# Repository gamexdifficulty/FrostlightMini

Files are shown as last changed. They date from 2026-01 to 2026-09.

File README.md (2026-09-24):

<p align="center">
  FrostlightMini Logo
</p>

<h1 align="center" id="title">FrostlightMini</h1>

<p align="center" id="description">
  A very small battery powered open source LED lamp.
</p>

<p align="center">
  
  
  
  
  
  
  
</p>

> ⚠️ This lamp is still work in progress and not a final product.

## ✨ Overview

FrostlightMini is a hand sized RGB LED lamp based on a custom PCB with an ESP32-C3 chip.
It can be used as a night light, party light, or small IoT device.

<p align="center">
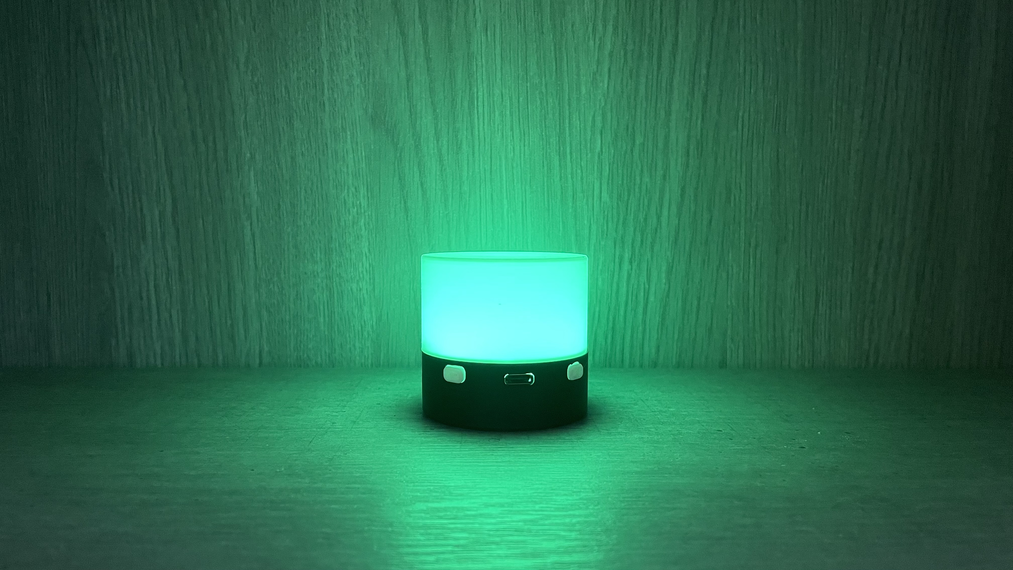
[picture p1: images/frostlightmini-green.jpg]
FrostlightMini Green
  
</p>

The project is fully open source and includes firmware, hardware design files, and documentation.

## 🔧 Hardware Features

<table>
<tr>
    <td width="60%" valign="top">

* Custom PCB  
* ESP32-C3 microcontroller with WiFi, ZigBee and Bluetooth  
* RGB LED  
* Battery powered  
* USB-C for charging and programming  
* Two physical buttons for control  

    </td>
    <td width="40%" align="center">
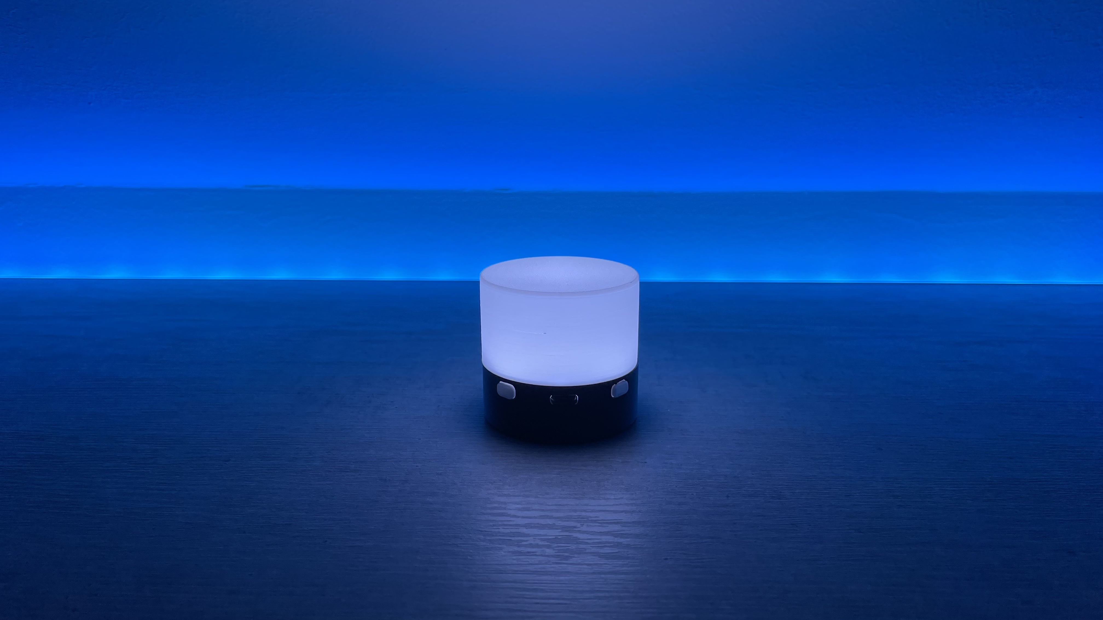
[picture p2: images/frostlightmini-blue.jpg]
FrostlightMini Blue
        
    </td>
</tr>
</table>

## 💡 Modes

FrostlightMini currently supports two operating modes:

* **Color Mode**
  Used to select and cycle through colors

* **Brightness Mode**
  Used to increase or decrease LED brightness

The lamp boots into **Color Mode** by default.

<p align="left">
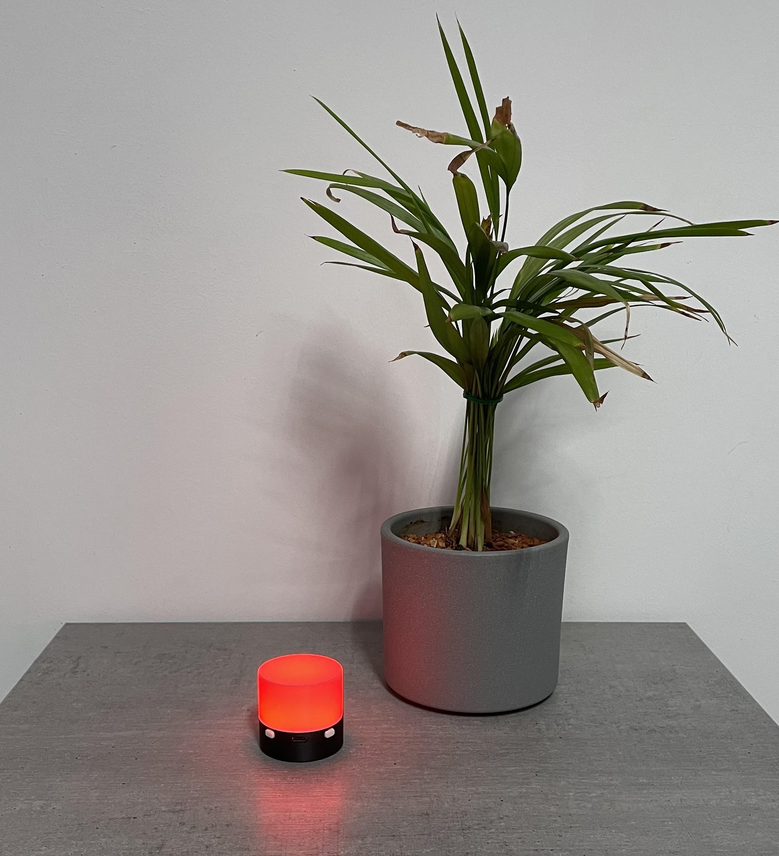
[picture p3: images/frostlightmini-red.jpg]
FrostlightMini Red
  
</p>

## 🎮 Controls

FrostlightMini is controlled using the **two buttons**.
Button behavior depends on the currently active mode.

### Button Overview

| Button | Purpose |
| --- | --- |
| Button 1 | Mode switching and power |
| Button 2 | Color or brightness control |

### Button 1, Mode & Power

<p align="left">
  Button 1
</p>

| Action | Effect |
| --- | --- |
| Short press | Switch between **Color Mode** and **Brightness Mode** |
| Hold ~1 second | Turn the lamp off |

Additional behavior:

* Entering **Color Mode** plays a color wheel animation
* Entering **Brightness Mode** is indicated by a short flash
* When powering off, the lamp flashes once, release the button to confirm shutdown

### Button 2, Mode Action Button

<p align="left">
  Button 2
</p>

#### In Color Mode

| Action | Effect |
| --- | --- |
| Short press | Switch directly to white |
| Hold | Cycle continuously through colors |

If the current color is white, holding the button starts cycling from red.

#### In Brightness Mode

| Action | Effect |
| --- | --- |
| Short press | Toggle between brightness increase and decrease |
| Hold | Continuously adjust brightness in the selected direction |

Additional behavior:

* A short flash indicates switching between increase/decrease
* Brightness Mode always starts in **decrease** mode

### 🔋 Charging Behavior

When the lamp is connected to power via USB-C, it enters a charging indicator mode.

| State | Indicator | How to exit |
| --- | --- | --- |
| Charging | Green pulsing light | Unplug USB-C or short-press any button |
| Fully charged | Blue pulsing light  | Short-press any button |

**Notes:**

* The charging indicator is shown automatically when the lamp is plugged in
* Pressing any button will return the lamp to normal operation while still plugged in

## 🔌 Power & Charging

* The lamp is powered by an internal lipo battery
* Charging is done via the USB-C port
* USB-C is also used for firmware flashing and development

## 🧑‍💻 Development

This project uses **PlatformIO** for firmware development.

Typical workflow:

* Open the project in PlatformIO
* Connect the lamp via USB-C
* Build and upload the firmware

## 📁 Repository Structure

* `firmware/` – ESP32-C3 firmware
* `hardware/` – PCB and hardware design files
* `images/` – Images used in this README
* `documentation/` – Additional documentation (if available)

## 🚧 Project Status

FrostlightMini is under active development.

Expect:

* Breaking changes
* Incomplete features
* Hardware and firmware revisions

Feedback, testing, and contributions are welcome.

## 🗺️ Roadmap

- [x] 0.1.0 | Basic functionality
- [x] 0.2.0 | Storing led state
- [x] 0.3.0 | Serial communication
- [x] 0.4.0 | Serial configuration
- [ ] 0.5.0 | Rewrite/Refactoring for better performance
- [ ] 0.6.0 | Permanent effects
- [ ] 0.7.0 | Desktop app
- [ ] 0.8.0 | Wireless communication
- [ ] 0.9.0 | Device synchronization
- [ ] 1.0.0 | Device hosted web app

## 🤝 Contributing

Contributions are appreciated.

You can help by:

* Reporting bugs
* Suggesting features
* Improving documentation
* Submitting pull requests

Please open an issue before making major changes.

## 📜 License

This project is licensed under the license specified in the repository.
See the `LICENSE` file for details.

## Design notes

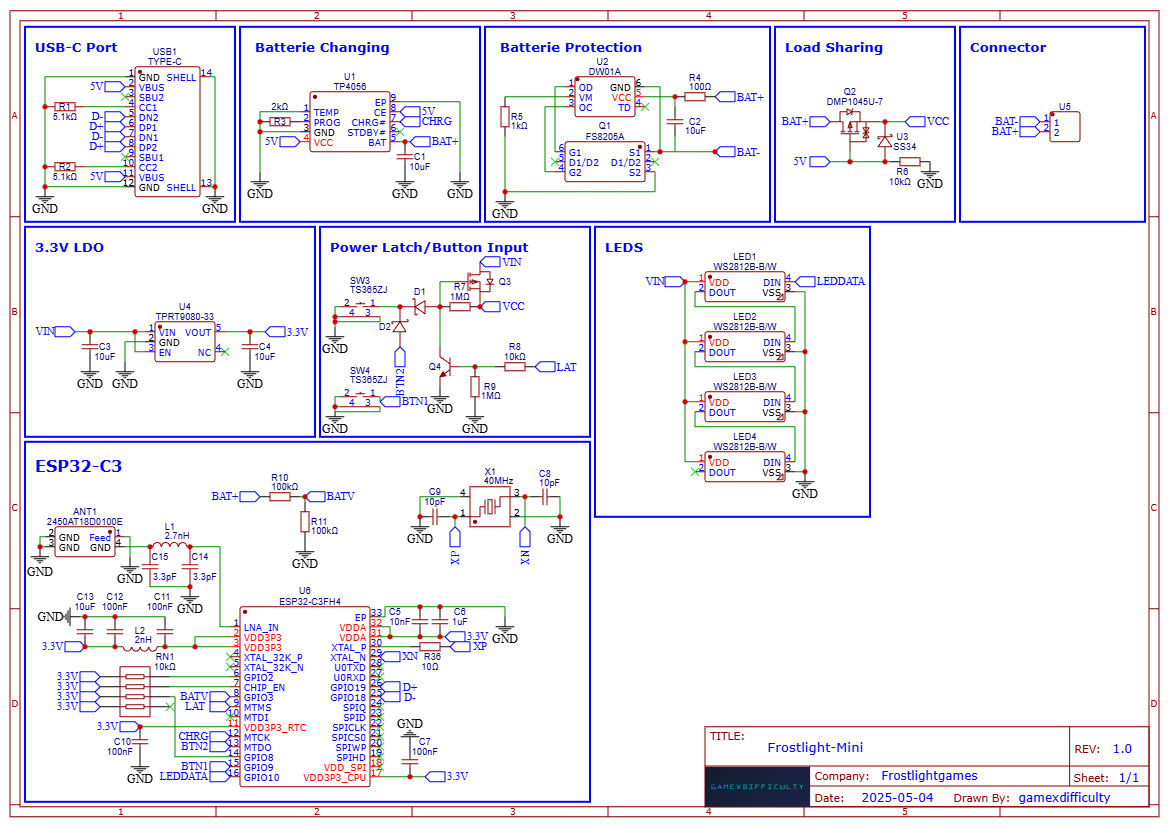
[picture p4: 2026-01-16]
hardware/schematics/frostlightmini-schematic.png

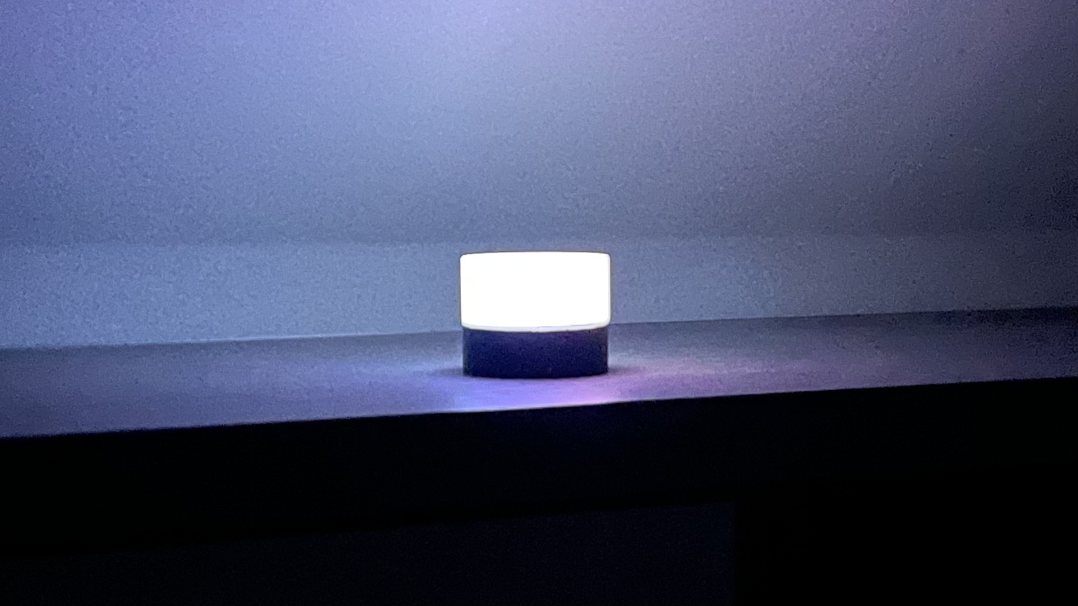
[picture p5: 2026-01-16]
images/lamp-white.jpg

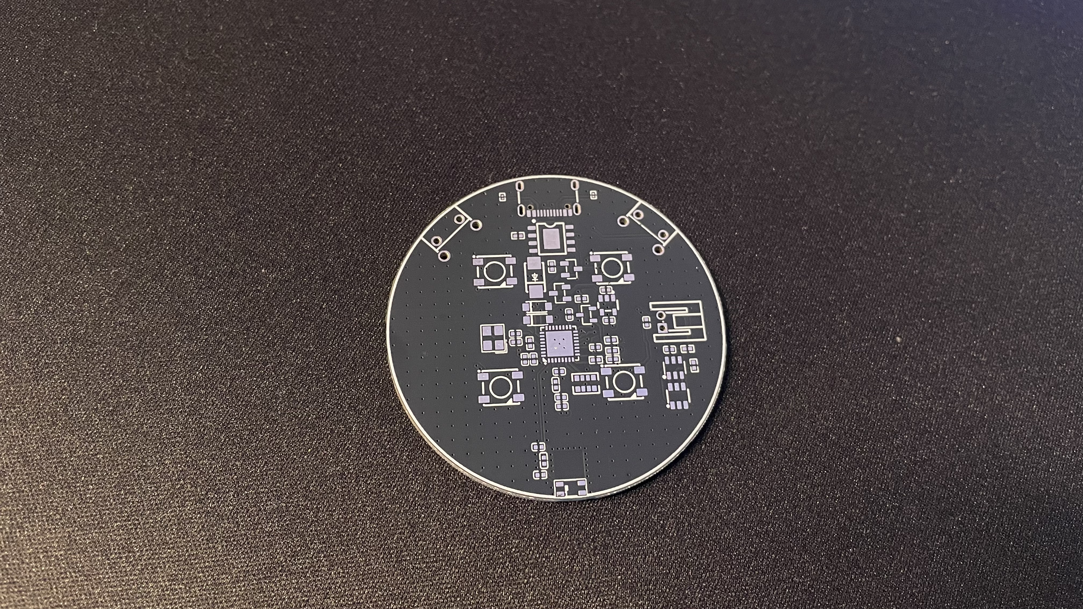
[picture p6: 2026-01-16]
images/pcb-top.jpg

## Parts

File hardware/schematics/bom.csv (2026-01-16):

ID | Name | Designator | Footprint | Quantity | Manufacturer Part | Manufacturer | Supplier | Supplier Part | Price
1 | 2450AT18D0100E | ANT1 | ANT-SMD_4P-L3.2-W1.6 | 1 | 2450AT18D0100E | JOHANSON(约翰逊) | LCSC | C2917718 | 0.674
2 | 10uF | C1,C2,C3,C4,C13 | C0402 | 5 | CL05A106MQ5NUNC | SAMSUNG(三星) | LCSC | C15525 | 0.005
3 | 10nF | C5 | C0402 | 1 | CC0402KRX7R9BB103 | YAGEO(国巨) | LCSC | C60133 | 0.001
4 | 1uF | C6 | C0402 | 1 | CL05A105KP5NNNC | SAMSUNG(三星) | LCSC | C14445 | 0.002
5 | 100nF | C7,C10,C11,C12 | C0402 | 4 | CL05B104KO5NNNC | SAMSUNG(三星) | LCSC | C1525 | 0.001
6 | 10pF | C8,C9 | C0402 | 2 | 0402CG100J500NT | FH(风华) | LCSC | C1545 | 0.001
7 | 3.3pF | C14,C15 | C0402 | 2 | GJM1555C1H3R3WB01D | muRata(村田) | LCSC | C88892 | 0.04
8 | BAT42W | D1,D2 | SOD-123_L2.8-W1.8-LS3.7-RD | 2 | BAT42W | SHIKUES(时科) | LCSC | C130886 | 0.027
9 | 2.7nH | L1 | L0402 | 1 | LQG15HS2N7S02D | muRata(村田) | LCSC | C77108 | 0.007
10 | 2nH | L2 | L0402 | 1 | LQG15HS2N0S02D | muRata(村田) | LCSC | C18216 | 0.008
11 | WS2812B-B/W | LED1,LED2,LED3,LED4 | LED-SMD_4P-L5.0-W5.0-TL_WS2812B-B | 4 | WS2812B-B/T | worldsemi | LCSC | C2761795 | 0.084
12 | FS8205A | Q1 | SOT-23-6_L2.9-W1.6-P0.95-LS2.8-BR | 1 | FS8205A | TECH PUBLIC(台舟) | LCSC | C2830320 | 0.046
13 | DMP1045U-7 | Q2 | SOT-23-3_L2.9-W1.3-P1.90-LS2.4-BR | 1 | DMP1045U-7 | DIODES(美台) | LCSC | C177033 | 0.075
14 | SI2301_C2891731 | Q3 | SOT-23-3_L2.9-W1.3-P1.90-LS2.4-BR | 1 | SI2301 | YONGYUTAI(永裕泰) | LCSC | C2891731 | 0.013
15 | S8050_C20069125 | Q4 | SOT-23-3_L2.9-W1.3-P1.90-LS2.3-BR | 1 | S8050 | 宏嘉诚 | LCSC | C20069125 | 0.01
16 | 5.1kΩ | R1,R2 | R0201 | 2 | 0201WMF5101TEE | UNI-ROYAL(厚声) | LCSC | C270344 | 0.001
17 | 2kΩ | R3 | R0402 | 1 | 0402WGF2001TCE | UNI-ROYAL(厚声) | LCSC | C4109 | 0.001
18 | 100Ω | R4 | R0402 | 1 | 0402WGF1000TCE | UNI-ROYAL(厚声) | LCSC | C25076 | 0.001
19 | 1kΩ | R5 | R0402 | 1 | RC0402FR-071KL | YAGEO(国巨) | LCSC | C106235 | 0.001
20 | 10kΩ | R6,R8 | R0402 | 2 | RC0402FR-0710KL | YAGEO(国巨) | LCSC | C60490 | 0.001
21 | 1MΩ | R7,R9 | R0402 | 2 | RC0402FR-071ML | YAGEO(国巨) | LCSC | C138033 | 0.001
22 | 100kΩ | R10,R11 | R0402 | 2 | RC0402FR-07100KL | YAGEO(国巨) | LCSC | C60491 | 0.001
23 | 10Ω | R36 | R0402 | 1 | 0402WGF100JTCE | UNI-ROYAL(厚声) | LCSC | C25077 | 0.001
24 | 10kΩ | RN1 | RES-ARRAY-SMD_0603-8P-L3.2-W1.6-BL | 1 | 4D03WGJ0103T5E | UNI-ROYAL(厚声) | LCSC | C29718 | 0.006
25 | TS365ZJ | SW3,SW4 | KEY-TH_TS365ZJ | 2 | TS365ZJ | SHOU HAN(首韩) | LCSC | C557598 | 0.051
26 | TP4056 | U1 | ESOP-8_L4.9-W3.9-P1.27-LS6.0-BL-EP | 1 | TP4056 | TECH PUBLIC(台舟) | LCSC | C5311018 | 0.087
27 | DW01A | U2 | SOT-23-6_L2.9-W1.6-P0.95-LS2.8-BL | 1 | DW01A | PUOLOP(迪浦) | LCSC | C351410 | 0.041
28 | SS34 | U3 | DO-214AC_L4.3-W2.7-LS5.2-RD | 1 | SS34 | YFW(佑风微) | LCSC | C3039962 | 0.036
29 | TPRT9080-33 | U4 | SOT-23-5_L2.9-W1.6-P0.95-LS2.8-BR | 1 | TPRT9080-33GJ5 | TECH PUBLIC(台舟) | LCSC | C2959864 | 0.105
30 | S2B-PH-K-S(LF)(SN) | U5 | CONN-TH_S2B-PH-K-S-LF-SN | 1 | S2B-PH-K-S(LF)(SN) | JST | LCSC | C173752 | 0.035
31 | ESP32-C3FH4 | U6 | QFN-32_L5.0-W5.0-P0.50-TL-EP3.7 | 1 | ESP32-C3FH4 | ESPRESSIF(乐鑫) | LCSC | C2858491 | 2.334
32 | TYPE-C | USB1 | USB-C-SMD_TYPE-C-6PIN-2MD-073 | 1 | TYPE-C 16PIN 2MD(073) | SHOU HAN(首韩) | LCSC | C2765186 | 0.063
33 | 40MHz | X1 | CRYSTAL-SMD_4P-L3.2-W2.5-BL | 1 | 7B040000M01 | HD(浩都频率) | LCSC | C655034 | 0.064

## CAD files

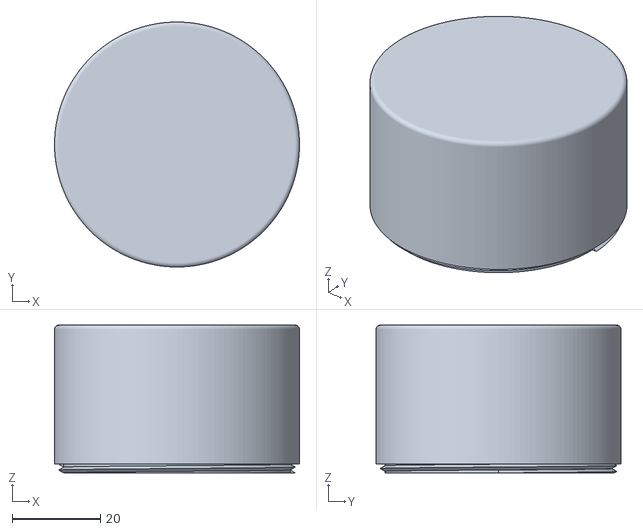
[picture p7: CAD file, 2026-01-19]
hardware/case/frostlightmini-top.stl
55.5 x 55.5 x 33.5

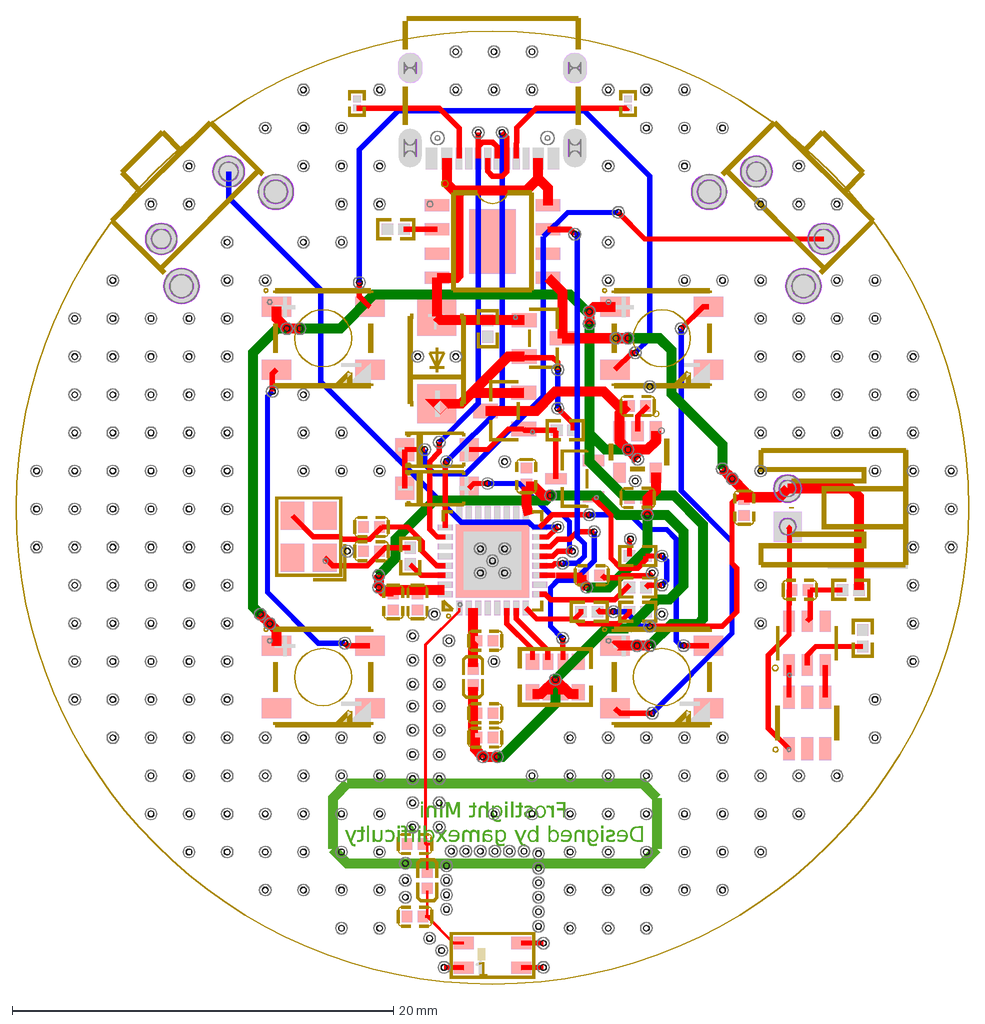
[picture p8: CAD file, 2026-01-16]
hardware/pcb/frostlightmini-pcb.dxf
gamexdifficulty
Frostlight Mini
Designed by
1

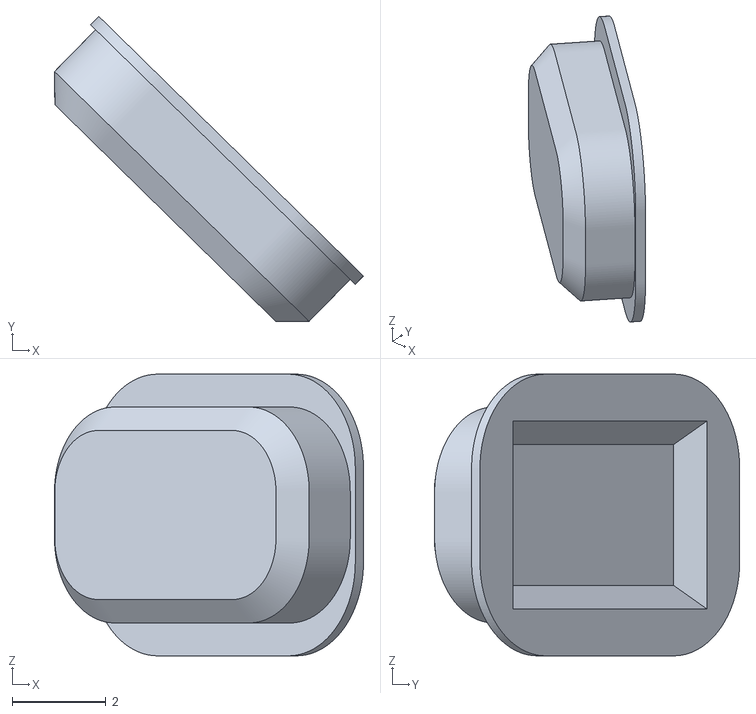
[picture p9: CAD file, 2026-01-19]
hardware/case/frostlightmini-button.stl
6.58 x 6.50 x 6.00

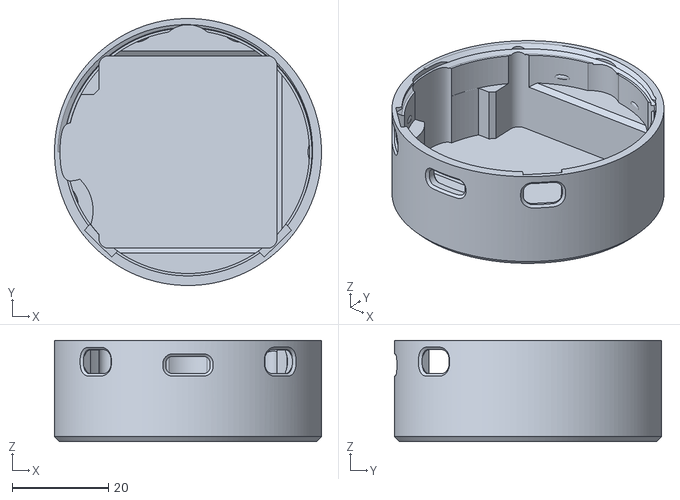
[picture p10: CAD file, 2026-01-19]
hardware/case/frostlightmini-case.stl
55.5 x 55.5 x 21.0

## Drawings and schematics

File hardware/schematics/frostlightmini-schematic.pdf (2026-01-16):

## USB-C Port

Batterie Changing | Batterie Protection

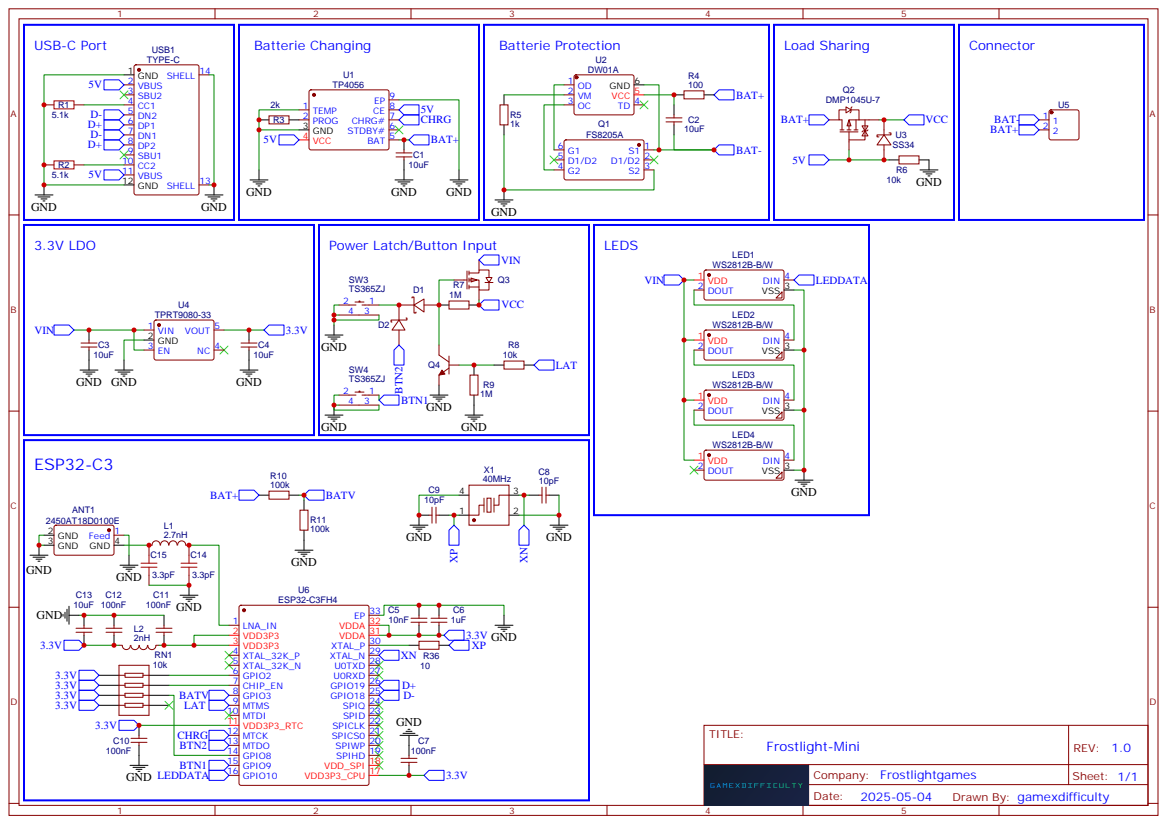
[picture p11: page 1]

Power Latch/Button Input

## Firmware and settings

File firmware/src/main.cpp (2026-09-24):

#include <stdio.h>
#include <cmath>
#include <algorithm>
#include <iostream>
#include <string>

#include "esp_log.h"
#include "esp_timer.h"
#include "freertos/FreeRTOS.h"
#include "freertos/task.h"

#include "pin.h"
#include "leds.h"
#include "serial.h"
#include "storage.h"

static const uint32_t LOOP_DELAY_MS = 20;
static const uint16_t SHORT_PRESS = 350;

extern "C" void app_main(void)
{
    const char* firmwareVersion = "0.4.0";

    Pin pins;
    Leds leds;
    Storage storage;
    LedConfig config;
    Serial serial;

    float hue = 0.0f;

    uint32_t lastTime = 0;
    uint32_t deltaTime = 0;
    uint16_t shutdownFlashCooldown = 0;

    bool shutdown = false;
    bool charging = false;
    bool interaction = false;

    uint8_t mode = 0;
    uint8_t savedMode = 0;
    uint8_t brightnessMode = 0;

    leds.clear();

    uint8_t savedColor[3] = {leds.getLedColor(0)[0],leds.getLedColor(0)[1],leds.getLedColor(0)[2]};

    if (!storage.loadLedConfig(config)) {
        leds.setBrightness(255);
        leds.setColor(0,0,0,0);
        leds.setColor(1,0,0,0);
        leds.setColor(2,0,0,0);
        leds.setColor(3,0,0,0);
        leds.startFadeToColor(255,255,255);
        savedColor[0] = 255;
        savedColor[1] = 255;
        savedColor[2] = 255;
    } else {
        leds.setBrightness(config.brightness);
        leds.setColor(0,0,0,0);
        leds.setColor(1,0,0,0);
        leds.setColor(2,0,0,0);
        leds.setColor(3,0,0,0);
        leds.startFadeToColor(config.r,config.g,config.b);
        float h, s, v;
        leds.rgbToHsv(config.r, config.g, config.b,h,s,v);
        hue = h/360.0f;
        savedColor[0] = config.r;
        savedColor[1] = config.g;
        savedColor[2] = config.b;
    }

    leds.update(0);

    while (true) {
        uint32_t now = esp_timer_get_time() / 1000;
        if (lastTime == 0) {lastTime = now;}
        deltaTime = now-lastTime;
        lastTime = now;
        pins.update(now);
        serial.update();

        if (pins.getBatteryPercentage() <= 0) { shutdown = true; }
        if (pins.getButton1HeldTimer() >= 1000 && shutdownFlashCooldown == 0) { 
            leds.startShortFlashEffect(); 
            shutdownFlashCooldown = 3000;
        }
        if (shutdownFlashCooldown != 0) { shutdownFlashCooldown = std::max<uint16_t>(0,shutdownFlashCooldown-deltaTime); }
        if (pins.getButton1Released() || pins.getButton2Released()) { interaction = true; } else { interaction = false; }
        if (pins.getButton1Released() && pins.getButton1HeldTimer() >= 1000) { shutdown = true; }
        if (pins.getButton1Released() && pins.getButton1HeldTimer() <= SHORT_PRESS) {
            if (mode < 2 && !charging && interaction) {
                mode = mode == 0 ? 1 : 0;
                if (mode == 0) {
                    leds.startColorWheel();
                }
                if (mode == 1) {
                    brightnessMode = 0;
                    leds.startShortFlashEffect();
                }
            }
        }

        if (mode == 0) { // color
            if (pins.getButton2Released() && pins.getButton2HeldTimer() < SHORT_PRESS) { 
                if (leds.getLedColor(0)[0] != 255 || leds.getLedColor(0)[1] != 255 || leds.getLedColor(0)[2] != 255) { // set to white
                    leds.startFadeToColor(255,255,255);
                    config.r = 255;
                    config.g = 255;
                    config.b = 255;
                    config.brightness = leds.getBrightness();
                    storage.saveLedConfig(config);
                }
            }
            if (pins.getButton2Pressed() && pins.getButton2HeldTimer() >= SHORT_PRESS) { // change color
                if (leds.getLedColor(0)[0] == 255 && leds.getLedColor(0)[1] == 255 && leds.getLedColor(0)[2] == 255 && leds.getEffectCount() == 0) { // reset from white to red
                    leds.startFadeToColor(255,0,0);
                    hue = 0.0f;
                }
                
                if (leds.getEffectCount() == 0) {
                    hue += 0.0025f; // cycle color
                    if (hue >= 1.0f) hue -= 1.0f;
                    
                    uint8_t r, g, b;
                    leds.hsvToRgb(hue, 1.0f, 1.0f, r, g, b);
                    config.r = r;
                    config.g = g;
                    config.b = b;
                    config.brightness = leds.getBrightness();
                    storage.saveLedConfig(config);

                    for (int i = 0; i < 4; i++) {
                        leds.setColor(i, r, g, b);
                    }
                }
            }
        }
        
        if (mode == 1) { // brightness up/down
            if (pins.getButton2Released() && pins.getButton2HeldTimer() < SHORT_PRESS) { 
                brightnessMode = brightnessMode == 0 ? 1 : 0;
                if (brightnessMode == 0) { leds.startShortFlashEffect(); }
                if (brightnessMode == 1) { leds.startShortFlashEffect(); }
            }
            if (pins.getButton2Pressed() && pins.getButton2HeldTimer() >= SHORT_PRESS) {
                uint8_t brightness = leds.getBrightness();
                if (brightnessMode == 0) { leds.setBrightness(std::max<uint8_t>(2,brightness - 1)); }     // brightness down
                if (brightnessMode == 1) { leds.setBrightness(std::min<uint8_t>(254,brightness + 1)); }   // brightness up

                config.r = leds.getLedColor(0)[0];
                config.g = leds.getLedColor(0)[1];
                config.b = leds.getLedColor(0)[2];
                config.brightness = leds.getBrightness();
                storage.saveLedConfig(config);
            }
        }

        if (mode == 2) { // charge
            if (leds.getEffectCount() == 0 && shutdown == false) { leds.startBreathEffect(); }
            if (!pins.isCharging() && charging && pins.getBatteryPercentage() >= 85) {
                mode = 3;
                leds.startFadeToColor(0,0,255);
            }
        }

        if (mode == 3) { // fully charged
            if (leds.getEffectCount() == 0 && shutdown == false) {
                leds.startBreathEffect();
            }
        }

        if (pins.isCharging() && !charging) { // check if charging
            savedMode = mode;
            const uint8_t* color = leds.getLedColor(0);
           
            if (color[0] != 0 || color[1] != 0 || color[2] != 0) {
                savedColor[0] = color[0];
                savedColor[1] = color[1]; 
                savedColor[2] = color[2];
            }
            leds.startFadeToColor(0,255,0);
            mode = 2;
        }

        auto tokens = serial.read();
        int tokenSize = tokens.size();
        if (!tokens.empty()) {
            if(tokens[0] == "off") {
                ESP_LOGI("Frostlight", "Shuting device off");
                shutdown = true;
            }

            if (tokens[0] == "set" && tokenSize > 1) {
                if (tokens[1] == "brightness" && tokenSize == 3) {
                    uint8_t brightness = stoi(tokens[2]);
                    if (brightness > 0) {
                        leds.setBrightness(brightness);
                        ESP_LOGI("Frostlight", "Set Brightness to %d", brightness);
                    } else {
                        ESP_LOGI("Frostlight", "Brightness must be between 1 and 255");
                    }
                } else if (tokens[1] == "color" && tokenSize == 5) {
                    uint8_t r = stoi(tokens[2]);
                    uint8_t g = stoi(tokens[3]);
                    uint8_t b = stoi(tokens[4]);
                    if (r == 0 && b == 0 && b == 0) {
                        ESP_LOGI("Frostlight", "Color must not be 0 0 0!");
                    } else {
                        for (int i=0; i<4; i++){
                            leds.setColor(i,r,g,b);
                        }
                        ESP_LOGI("Frostlight", "Set Color to R:%d G:%d B:%d", r,g,b);
                    }
                }
            }

            if (tokens[0] == "get" && tokenSize > 1) {
                if(tokens[1] == "version") {
                    ESP_LOGI("Frostlight", "%s", firmwareVersion);
                } else if(tokens[1] == "color") {
                    ESP_LOGI("Frostlight", "%d, %d, %d", leds.getLedColor(0)[0], leds.getLedColor(0)[1], leds.getLedColor(0)[2]);
                } else if(tokens[1] == "brightness") {
                    ESP_LOGI("Frostlight", "%d", leds.getBrightness());
                } else if(tokens[1] == "effectcount") {    
                    ESP_LOGI("Frostlight", "%d", leds.getEffectCount());
                }else if(tokens[1] == "temperature") {    
                    ESP_LOGI("Frostlight", "%.3f", pins.getChipTemperature());
                } else if(tokens[1] == "battery") {
                    ESP_LOGI("Frostlight", "%.3f, %d, %s", pins.getADC(), pins.getBatteryPercentage(), pins.isCharging() ? "true" : "false"); // voltage, percentage, charging 
                } else if(tokens[1] == "remaining") {
                    float brightness = leds.getBrightness() / 255.0f;

                    float r = (leds.getLedColor(0)[0] / 255.0f) * brightness;
                    float g = (leds.getLedColor(0)[1] / 255.0f) * brightness;
                    float b = (leds.getLedColor(0)[2] / 255.0f) * brightness;

                    float red   = 20.0f * r;
                    float green = 20.0f * g;
                    float blue  = 20.0f * b;

                    float current = (red + green + blue) * 4.0f;

                    float remaining = 0.0f;
                    if (current > 0.001f) {
                        remaining = (2000.0f / current) * (pins.getBatteryPercentage() / 100.0f);
                    }

                    ESP_LOGI("Frostlight", "%.3f %.3f", remaining, current); // hours, current in mAh

                }
            }
        }

        if (((!pins.isCharging() && charging) && mode == 2) || (interaction && mode > 1)) { // unplugged or interacted with
            mode = savedMode;
            leds.startFadeToColor(savedColor[0], savedColor[1], savedColor[2]);
        }

        charging = pins.isCharging();

        if (shutdown) { // shutoff
            leds.darkenOff();
            if (leds.getBrightness() <= 0) {
                pins.turnOff();
            }
        }

        leds.update(deltaTime);
        vTaskDelay(pdMS_TO_TICKS(LOOP_DELAY_MS));
    }
}

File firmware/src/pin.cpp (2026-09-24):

#include "pin.h"
#include "math.h"

#include "driver/gpio.h"
#include "driver/adc.h"
#include "driver/temperature_sensor.h"
#include "esp_adc_cal.h"
#include "esp_log.h"

/* GPIO definitions */
#define PWR_GPIO GPIO_NUM_4
#define CHRG_GPIO GPIO_NUM_6
#define BUTTON1GPIO GPIO_NUM_7
#define BUTTON2GPIO GPIO_NUM_9

/* ADC definitions */
#define ADC_CHANNEL ADC1_CHANNEL_3
#define ADC_WIDTH ADC_WIDTH_BIT_12
#define ADC_ATTEN ADC_ATTEN_DB_11
#define DEFAULT_VREF 1100

static esp_adc_cal_characteristics_t adc_chars;

Pin::Pin() {
    /* Power GPIO */
    gpio_config_t pwr_conf = {};
    pwr_conf.pin_bit_mask = (1ULL << PWR_GPIO);
    pwr_conf.mode = GPIO_MODE_OUTPUT;
    pwr_conf.pull_up_en = GPIO_PULLUP_DISABLE;
    pwr_conf.pull_down_en = GPIO_PULLDOWN_DISABLE;
    pwr_conf.intr_type = GPIO_INTR_DISABLE;
    gpio_config(&pwr_conf);
    gpio_set_level(PWR_GPIO, 1);

    /* CHRG pin */
    gpio_config_t chrg_conf = {};
    chrg_conf.pin_bit_mask = (1ULL << CHRG_GPIO);
    chrg_conf.mode = GPIO_MODE_INPUT;
    chrg_conf.pull_up_en = GPIO_PULLUP_ENABLE;
    chrg_conf.pull_down_en = GPIO_PULLDOWN_DISABLE;
    chrg_conf.intr_type = GPIO_INTR_DISABLE;
    gpio_config(&chrg_conf);

    /* Button GPIOs */
    gpio_config_t btn_conf = {};
    btn_conf.pin_bit_mask =
        (1ULL << BUTTON1GPIO) |
        (1ULL << BUTTON2GPIO);
    btn_conf.mode = GPIO_MODE_INPUT;
    btn_conf.pull_up_en = GPIO_PULLUP_ENABLE;
    btn_conf.pull_down_en = GPIO_PULLDOWN_DISABLE;
    btn_conf.intr_type = GPIO_INTR_DISABLE;
    gpio_config(&btn_conf);

    /* ADC setup */
    adc1_config_width(ADC_WIDTH);
    adc1_config_channel_atten(ADC_CHANNEL, ADC_ATTEN);

    esp_adc_cal_characterize(
        ADC_UNIT_1,
        ADC_ATTEN,
        ADC_WIDTH,
        DEFAULT_VREF,
        &adc_chars);

    /* Temperature setup */
    temp_handle = NULL;
    temperature_sensor_config_t temp_sensor = {
        .range_min = -10,
        .range_max = 80,
    };
    ESP_ERROR_CHECK(temperature_sensor_install(&temp_sensor, &temp_handle));
    ESP_ERROR_CHECK(temperature_sensor_enable(temp_handle));

}

void Pin::update(uint32_t timer) {
    bool btn1Now = (gpio_get_level(BUTTON1GPIO) == 0);
    bool btn2Now = (gpio_get_level(BUTTON2GPIO) == 0);

    if (!button1Initialized) {
        button1Initialized = !btn1Now;
    } else {
        button1Released = (button1Pressed && !btn1Now);
        button1Pressed = btn1Now;
    }

    if (!button2Initialized) {
        button2Initialized = !btn2Now;
    } else {
        button2Released = (button2Pressed && !btn2Now);
        button2Pressed = btn2Now;
    }

    if (button1Pressed && button1HeldStartTimer == 0) { button1HeldStartTimer = timer; }
    if (button2Pressed && button2HeldStartTimer == 0) { button2HeldStartTimer = timer; }

    if (button1HeldStartTimer != 0) { button1HeldTimer = timer - button1HeldStartTimer; }
    if (button2HeldStartTimer != 0) { button2HeldTimer = timer - button2HeldStartTimer; }

    if (!button1Pressed and !button1Released and button1HeldStartTimer > 0) {
        button1HeldStartTimer = 0;
        button1HeldTimer = 0;
    }

    if (!button2Pressed and !button2Released and button2HeldStartTimer > 0) {
        button2HeldStartTimer = 0;
        button2HeldTimer = 0;
    }

    if (monitorBattery && timer - batteryMonitoringTimer > 3000) {
        ESP_LOGI("Frostlight", "Battery voltage: %.3f | Battery charge percentage: %d | Charging: %s", getADC(), getBatteryPercentage(),isCharging() ? "true" : "false");
        batteryMonitoringTimer = timer;
    }
}

bool Pin::getButton1Pressed() { return button1Pressed; }
bool Pin::getButton2Pressed() { return button2Pressed; }
bool Pin::getButton1Released() { return button1Released; }
bool Pin::getButton2Released() { return button2Released; }

uint32_t Pin::getButton1HeldTimer() { return button1HeldTimer; }
uint32_t Pin::getButton2HeldTimer() { return button2HeldTimer; }

float Pin::getADC() {
    int raw = adc1_get_raw(ADC_CHANNEL);
    uint32_t mv = esp_adc_cal_raw_to_voltage(raw, &adc_chars);

    float adc_voltage = mv / 1000.0f;
    return adc_voltage * 2.0f;
}

int Pin::getBatteryPercentage() {
    float v = getADC();
    int percent = 100.0f * powf((v - 3.3f) / 0.9f, 1.6f);
    
    if (percent > 100) percent = 100;
    if (percent < 0) percent = 0;
    
    return percent;
}

float Pin::getChipTemperature() {
    float tsens_out = 0;
    temperature_sensor_get_celsius(temp_handle, &tsens_out);
    return tsens_out;
}

bool Pin::isCharging() { return gpio_get_level(CHRG_GPIO) == 0; }
void Pin::turnOff() { gpio_set_level(PWR_GPIO, 0); }

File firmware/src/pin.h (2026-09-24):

#ifndef _PIN_H_
#define _PIN_H_

#include <cstdint>
#include "driver/temperature_sensor.h"

class Pin {
private:
    bool monitorBattery = false;
    bool button1Pressed = false;
    bool button2Pressed = false;
    bool button1Released = false;
    bool button2Released = false;
    bool button1Initialized = false;
    bool button2Initialized = false;
    uint32_t button1HeldTimer = 0;
    uint32_t button2HeldTimer = 0;
    uint32_t button1HeldStartTimer = 0;
    uint32_t button2HeldStartTimer = 0;
    uint32_t batteryMonitoringTimer = 0;
    temperature_sensor_handle_t temp_handle = NULL;
    
public:
    Pin();
    void setBatteryMonitoring(bool state) {monitorBattery = state;};
    void update(uint32_t timer);
    void turnOff();

    float getADC();
    bool isCharging();
    int getBatteryPercentage();
    float getChipTemperature();

    bool getButton1Pressed();
    bool getButton2Pressed();
    bool getButton1Released();
    bool getButton2Released();

    uint32_t getButton1HeldTimer();
    uint32_t getButton2HeldTimer();
};

#endif

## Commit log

2026-01-16 Added schematics
    [bom.csv, frostlightmini-schematic-altium.schdoc]
2026-01-16 Added pcb files
    [frostlightmini-pcb-altium.pcbdoc, frostlightmini-pcb.dxf]
2026-01-16 Added current case version
    [frostlightmini-case.stl]
2026-01-16 Added current firmware version
    [partitions.csv]
2026-01-16 Added picture of pcb
2026-01-19 Updated 3d files for lamp case
    [frostlightmini-button.stl, frostlightmini-case.stl, frostlightmini-top.stl]
2026-01-19 Fixed transition from white to red being instant
    [main.cpp]
2026-01-19 Fixed partitioning for spiffs
    [partitions.csv]
2026-01-21 Added charging effect pause, when shutdown
2026-01-22 Added battery monitoring via serial
2026-01-24 Disabled automatic battery monitor
2026-01-24 Added simple serial communication to device
2026-01-26 Fixed lamp not lighting up when unplugged
    [main.cpp]
2026-02-01 Fixed brightness to not be set to 0
    [main.cpp]
2026-02-04 Added chip temperature readout
2026-02-05 Added command to readout temperature via serial
2026-10-21 Fixed button logic, when leaving charge mode
